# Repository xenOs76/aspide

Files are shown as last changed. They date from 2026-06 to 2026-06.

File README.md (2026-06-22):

# Aspide

<p align="center">
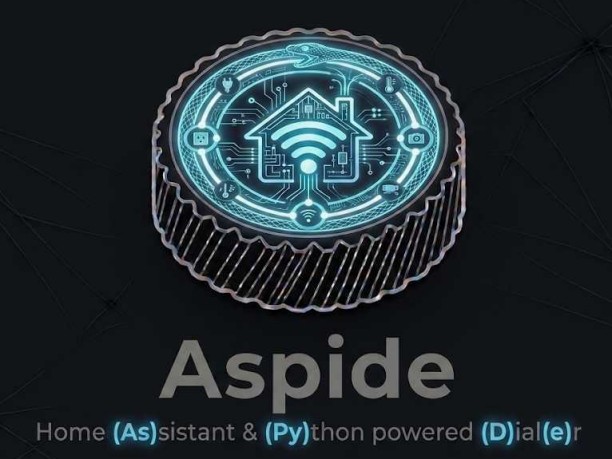
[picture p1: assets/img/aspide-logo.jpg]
Aspide Logo
    
</p>

**Aspide** is a smart, tactile, rotary controller built with
[CircuitPython](https://circuitpython.org/) for the Adafruit QT Py ESP32-S2
board.\
This device provides a physical interface to control
[Home Assistant](https://www.home-assistant.io/) scenes and lights with rich
visual feedback via a NeoPixel strip.

**Aspide** is inspired by two of the many, great, tutorials created by
[Adafruit](https://www.adafruit.com/):

- [USB Rotary Media Dial](https://learn.adafruit.com/usb-rotary-media-dial)
- [Control Wiz Lights With CircuitPython](https://learn.adafruit.com/control-wiz-lights-with-circuitpython/overview)

## Features

- **Triple Control Modes**: Switch between controlling _Home Assistant scenes_,
  _light effects_, and _brightness presets_.
- **NeoPixel Visual Feedback**:
  - Mode indicators (Blue for scenes, Amber for effects, White for brightness).
  - Scene/Effect/Brightness previews with colors matching the selected setting.
- **Home Assistant Integration**: Uses the HA REST API for reliable, low-latency
  control.
- **Manufacturer-Agnostic Light Control**: Controls any HA `light.*` entity
  through Home Assistant — no direct UDP or vendor-specific libraries required.
- **Inactivity Timer**: Automatically dims NeoPixels after a period of
  inactivity to save power and reduce light pollution.
- **HA Health Check**: Periodically verifies Home Assistant connectivity and
  reboots if unreachable after retries (automatic recovery).

## Screenshots

<details>
    <p align="center">
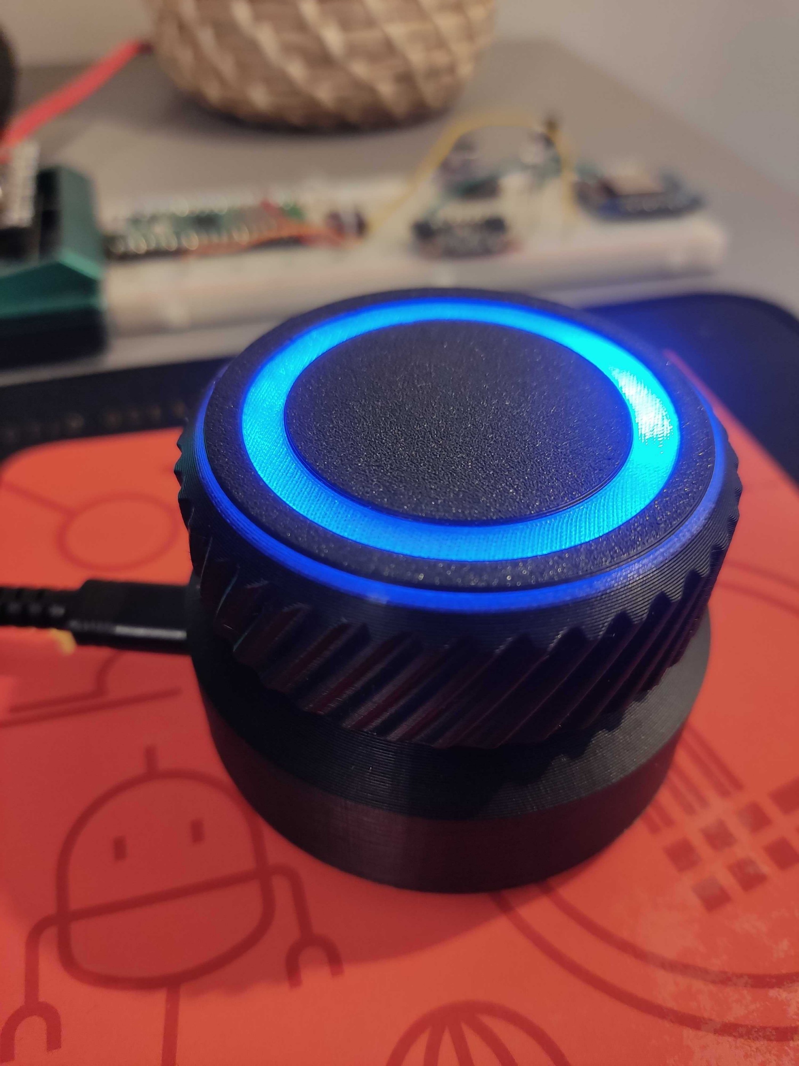
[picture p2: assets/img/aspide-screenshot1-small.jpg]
Aspide Screeenshot 1
        
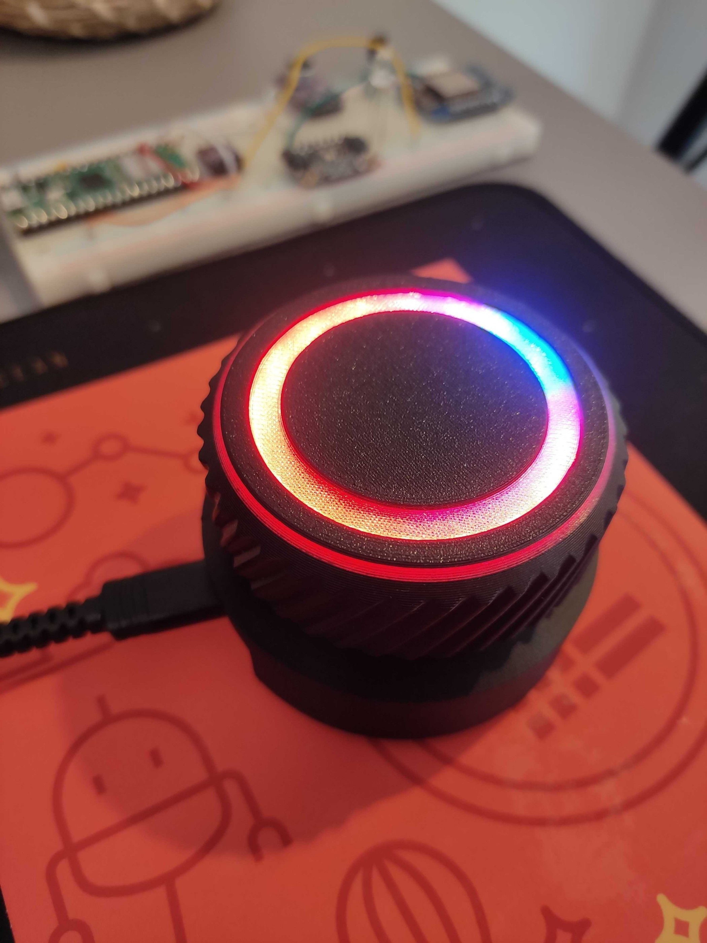
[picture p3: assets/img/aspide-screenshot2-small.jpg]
Aspide Screeenshot 1
        
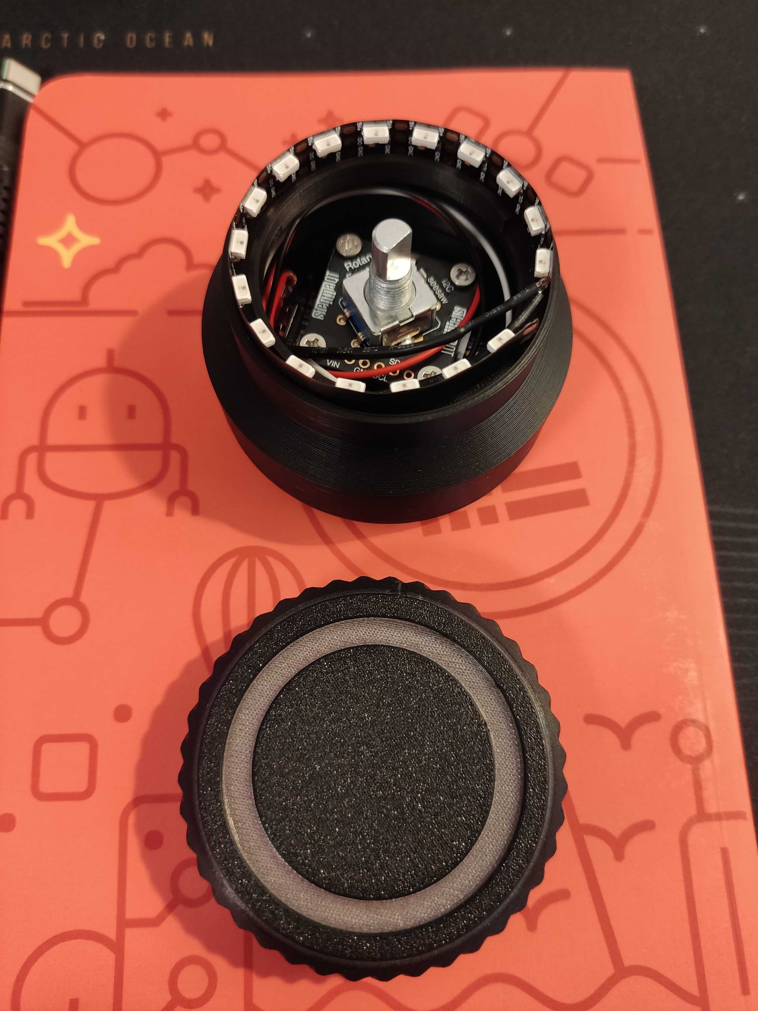
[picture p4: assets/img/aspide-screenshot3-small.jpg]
Aspide Screeenshot 1
        
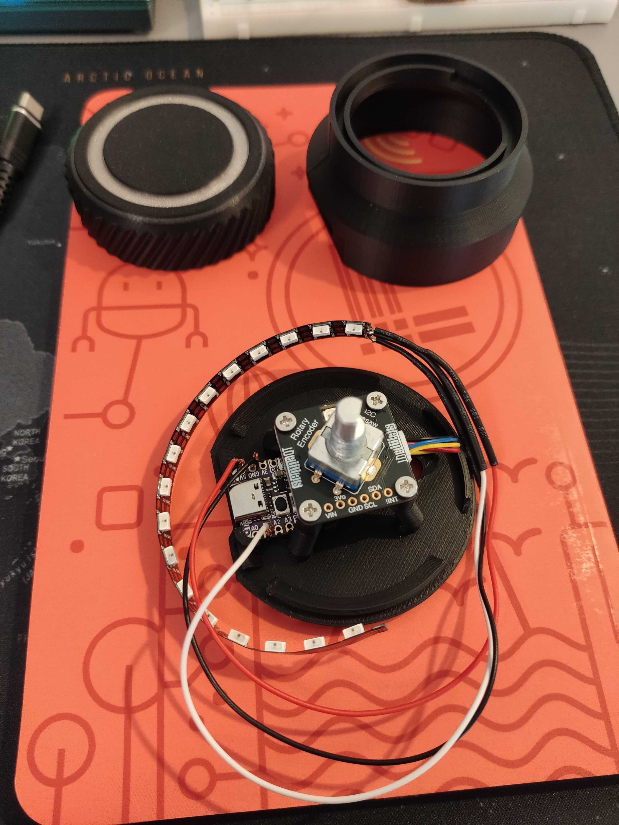
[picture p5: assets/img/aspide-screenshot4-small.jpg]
Aspide Screeenshot 1
        
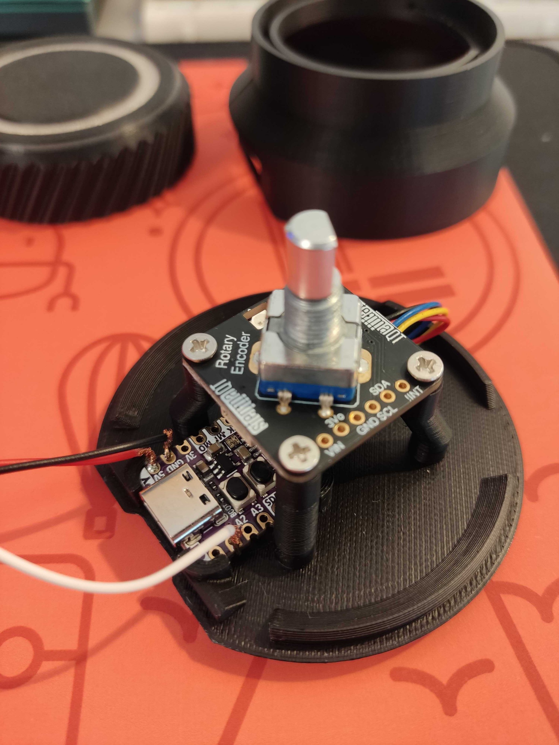
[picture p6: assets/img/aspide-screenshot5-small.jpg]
Aspide Screeenshot 1
        
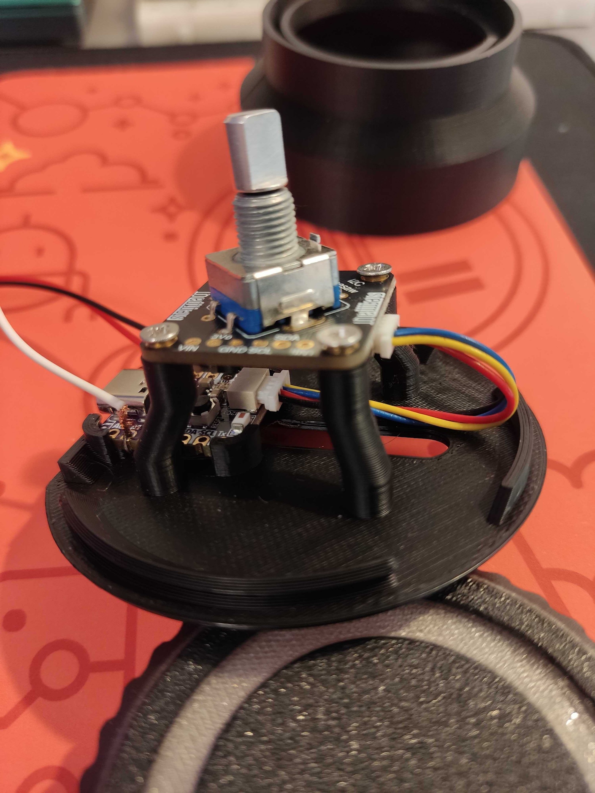
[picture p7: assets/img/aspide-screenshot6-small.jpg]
Aspide Screeenshot 1
        
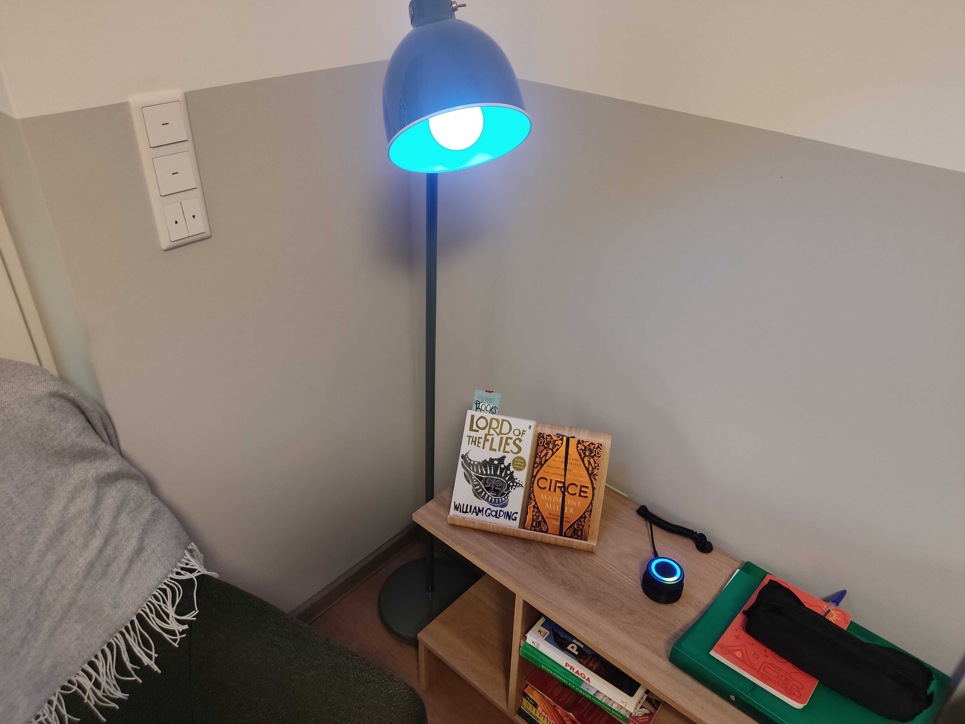
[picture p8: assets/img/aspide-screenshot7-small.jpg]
Aspide Screeenshot 1
        
    </p>
</details>

## Hardware Requirements

- **Microcontroller**:
  [Adafruit QT Py ESP32-S2 WiFi Dev Board with STEMMA QT](https://www.adafruit.com/product/5325)
- **Input**:
  [Adafruit I2C Stemma QT Rotary Encoder Breakout with Encoder - STEMMA QT / Qwiic](https://www.adafruit.com/product/5880)
- **Output**:
  [Adafruit NeoPixel LED Side Light Strip](https://www.adafruit.com/product/3634)
- **STEMMA cable**:
  [STEMMA QT / Qwiic JST SH 4-Pin Cable](https://www.adafruit.com/product/4399)
- **USB cable**:
  [USB A to USB C Cable](https://www.amazon.de/dp/B0D72YLKWL?ref=ppx_yo2ov_dt_b_fed_asin_title&th=1)
- **Power cable**:
  [Stranded-Core Ribbon Cable - 4 Wires](https://www.adafruit.com/product/3891)
  or 3 single cables (stranded)
- **Enclosure**:
  [3D printed case](https://learn.adafruit.com/usb-rotary-media-dial/cad-files)
  for the
  [USB Rotary Media Dial](https://learn.adafruit.com/usb-rotary-media-dial)
- **Enclosure Screws**:
  [4 M2.5 x 6mm steel machine screws](https://www.amazon.de/-/en/dp/B01D4R5A1E?ref=ppx_yo2ov_dt_b_fed_asin_title)

### Cabling

<details>

<p align="center">
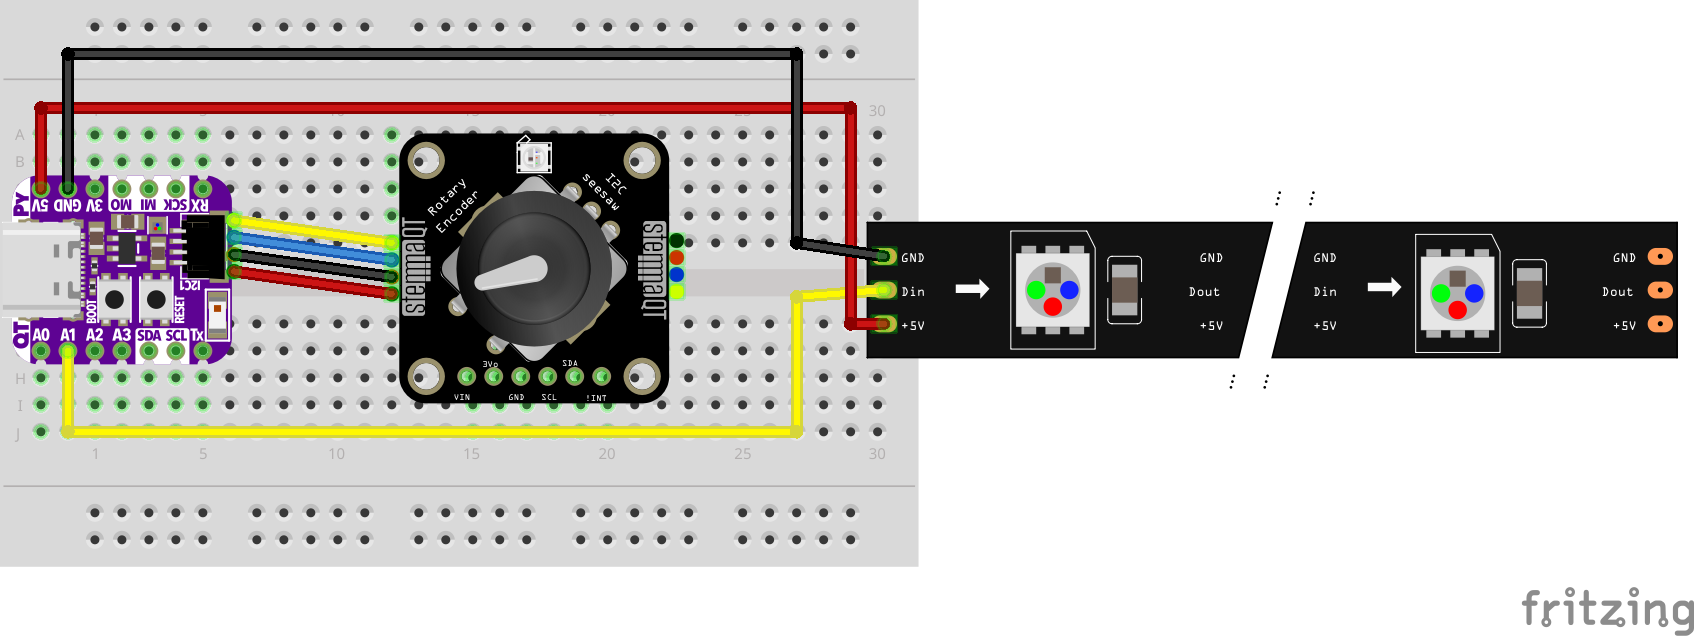
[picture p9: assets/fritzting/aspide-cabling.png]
Aspide Logo
    
</p>

</details>

## Configuration

The device is configured via a `settings.toml` file located in the root of the
`CIRCUITPY` drive.

### WiFi Settings

```toml
CIRCUITPY_WIFI_SSID = "Your_SSID"
CIRCUITPY_WIFI_PASSWORD = "Your_Password"
```

### Home Assistant Settings

To connect to Home Assistant, you need your server URL and a **Long-Lived Access
Token** (generated from your HA user profile).

```toml
HA_URL = "http://192.168.1.78:8123"
HA_TOKEN = "your_long_lived_access_token_here"

# List of HA scenes to iterate through in 'home_assistant' mode
HA_SCENES = "scene.nightlights,scene.lightsoff,scene.atdesk_soft_lights,scene.softlights1"

# Light entity for ha_light and ha_brightness modes
HA_LIGHT_ENTITY_ID = "light.wiz_01"

# Effects to browse in ha_light mode (comma-separated, must match HA effect_list)
# Leave empty to use built-in defaults: Warm White, Daylight, Sunset, Focus
HA_LIGHT_EFFECTS = "Warm White,Daylight,Sunset,Focus"

# NeoPixel preview colors for effects (1:1 with HA_LIGHT_EFFECTS; optional)
HA_LIGHT_EFFECT_COLORS = "bright_yellow,bright_white,dim_orange,dim_green"

# Brightness presets for ha_brightness mode (off=0, low=64, mid=128, high=191, max=255)
HA_LIGHT_BRIGHTNESS = "off,low,mid,high,max"

# Optional NeoPixel preview override (1:1 with HA_LIGHT_BRIGHTNESS)
# If omitted, preview scales white to match each preset's HA brightness
# HA_LIGHT_BRIGHTNESS_COLORS = ""
```

### NeoPixel Customization

Customize the behavior and appearance of the LED ring.

```toml
# Seconds of inactivity before NeoPixels turn off
NEOPIXEL_TIMEOUT = 30

# Colors for HA scenes (maps 1-to-1 with HA_SCENES above)
# Available intensities: bright_, soft_, dim_
# Available colors: white, green, red, blue, purple, cyan, yellow, orange, pink, gold, black
HA_SCENE_COLORS = "dim_blue,black,soft_white,dim_white"
```

## Operation

### Controls

- **Rotate**: Browse through the available scenes, effects, or brightness
  presets. The NeoPixel ring will change color to provide a preview.
- **Single Push**: Activate the currently selected scene, effect, or brightness
  preset.
- **Double Push**: Perform a hard reset of the device (reboots and reconnects to
  WiFi).
- **Long Push**: Cycle through **Home Assistant Mode** (Blue), **Light Effects
  Mode** (Amber), and **Brightness Mode** (White).

### Modes

1. **Home Assistant Mode**: Cycles through the scenes defined in `HA_SCENES`.
   The NeoPixels will match the colors defined in `HA_SCENE_COLORS`.
2. **Light Effects Mode** (`ha_light`): Cycles through effects defined in
   `HA_LIGHT_EFFECTS`, or uses built-in defaults (Warm White, Daylight, Sunset,
   Focus) when empty. Effect names must match what your light integration
   exposes. NeoPixel preview colors come from `HA_LIGHT_EFFECT_COLORS`.
3. **Brightness Mode** (`ha_brightness`): Cycles through five presets in
   `HA_LIGHT_BRIGHTNESS` (default: off, low, mid, high, max — 0% to 100% in 25%
   steps). Single push sends `light.turn_on` with the corresponding brightness
   level. NeoPixel preview scales white to match each preset unless overridden
   via `HA_LIGHT_BRIGHTNESS_COLORS`.

### HA connectivity

Every 5 minutes (configurable via optional `HA_PHONE_HOME_INTERVAL`), the device
pings Home Assistant. If the API is unreachable, it retries twice at 5-second
intervals (reconnecting WiFi if needed), then reboots to recover device-side
network state. If Home Assistant remains down, this cycle repeats each interval
until HA responds.

## Installation

1. [Install CircuitPython on your QT Py ESP32-S2](https://learn.adafruit.com/adafruit-qt-py-esp32-s2/circuitpython)
2. Copy the contents of the `src/` directory to the root of your `CIRCUITPY`
   drive
3. Make sure all the required libraries have been copied into the `lib/` folder
4. Use `settings.sample.toml` as template to configure your `settings.toml`
5. Enjoy!

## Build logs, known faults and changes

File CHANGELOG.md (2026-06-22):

### 0.4.0 (2026-06-22)

- **Periodic HA phone-home**: `HomeAssistantClient.ping()` and
  `RotaryDial.phone_home_assistant()` verify HA connectivity every 5 minutes
  (default); retries twice at 5-second intervals with WiFi reconnect; reboots on
  persistent failure until HA recovers
- Optional `HA_PHONE_HOME_INTERVAL` setting; firmware default
  `DEFAULT_HA_PHONE_HOME_INTERVAL` (300 s) in `utils.py`

### 0.3.0 (2026-06-17)

- **Light effects** curated to four Wiz presets (Warm White, Daylight, Sunset,
  Focus) with matching NeoPixel preview colors; empty `HA_LIGHT_EFFECTS` uses
  built-in defaults instead of auto-fetching full `effect_list`
- **Brightness presets** expanded to five evenly spaced levels
  (off/low/mid/high/max: 0%, 25%, 50%, 75%, 100%); NeoPixel preview scales white
  to match HA brightness
- Sample scene list: `scene.redalert` replaced with `scene.atdesk_soft_lights`;
  NeoPixel preview colors updated (`soft_white`, `dim_white`)

### 0.2.0 (2026-06-17)

### Added

- **Light Effects mode** (`ha_light`): browse and apply HA `light.*` effects via
  `HA_LIGHT_EFFECTS` or auto-fetched `effect_list`
- **Brightness mode** (`ha_brightness`): dim/soft/bright presets via
  `HA_LIGHT_BRIGHTNESS`
- NeoPixel preview colors for effects and brightness (`HA_LIGHT_EFFECT_COLORS`,
  `HA_LIGHT_BRIGHTNESS_COLORS`)
- `AGENTS.md` — project-specific guidance for AI coding agents (commands,
  structure, boundaries)
- HA client support for `light.turn_on` with `effect` and `brightness`; entity
  state and effect list fetching

### Changed

- Replaced Wiz-specific control with manufacturer-agnostic HA light entity
  control (`HA_LIGHT_ENTITY_ID`)
- **Button mapping:** long push cycles modes; double push reboots (was reversed)
- Triple-mode operation: Home Assistant scenes, light effects, brightness
  presets
- NVM state format uses magic byte `0x43` with legacy `0x42` migration
- README and `settings.sample.toml` updated for new modes and config keys

### Removed

- `adafruit-circuitpython-wiz` dependency
- `HA_WIZ_LIGHT_ENTITY_ID` and Wiz-specific code paths

## 0.1.0 (2026-06-13)

### Feat

    Aspide CircuitPython application with rotary encoder and NeoPixel ring control
    Home Assistant scene integration and Wiz light effect support
    Button press detection (single/double/long) with inactivity timeout

### Docs

    Added README with configuration guide and setup instructions

### Chores

    Added project configuration files, development tooling, and environment setup

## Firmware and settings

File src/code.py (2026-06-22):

"""Main entry point for the Aspide firmware.

This script initializes the hardware (Rotary Encoder, NeoPixels, I2C),
manages the WiFi connection, and runs the main event loop for handling
user interactions (rotations, single/double/long pushes) to control
Home Assistant entities.
"""

import time
import microcontroller
import os

from adafruit_seesaw import digitalio, rotaryio, seesaw
import neopixel
import board

from colors import rgb_colors
from timeout import InactivityTimer
from ui import DisplayManager
from utils import ButtonPush, DEFAULT_HA_PHONE_HOME_INTERVAL, RotaryDial

# --- Hardware Initialization ---

i2c = board.STEMMA_I2C()  # Using built-in STEMMA QT connector
seesaw = seesaw.Seesaw(i2c, addr=0x36)
seesaw_product = (seesaw.get_version() >> 16) & 0xFFFF
print(f"Found product {seesaw_product}")

if seesaw_product != 4991:
    print("Warning: Unexpected seesaw product ID. Expected 4991")

# Button setup on seesaw pin 24
seesaw.pin_mode(24, seesaw.INPUT_PULLUP)
button = digitalio.DigitalIO(seesaw, 24)
button_held = False

# NeoPixel Ring setup
pixel_pin = board.A1
num_pixels = 18
strip = neopixel.NeoPixel(pixel_pin, num_pixels, brightness=0.5, auto_write=True)

# --- State Management ---

last_position = -1
position_direction = None
color = 0
color_step = 5

encoder = rotaryio.IncrementalEncoder(seesaw)
push = ButtonPush()
rotary_dial = RotaryDial()

# Custom Scene Color Parsing
ha_scene_colors_str = os.getenv("HA_SCENE_COLORS", "")
ha_scene_colors = (
    [c.strip() for c in ha_scene_colors_str.split(",")] if ha_scene_colors_str else []
)

ha_light_effect_colors_str = os.getenv("HA_LIGHT_EFFECT_COLORS", "")
ha_light_effect_colors = (
    [c.strip() for c in ha_light_effect_colors_str.split(",")]
    if ha_light_effect_colors_str
    else []
)

ha_brightness_colors_str = os.getenv("HA_LIGHT_BRIGHTNESS_COLORS", "")
ha_brightness_colors = (
    [c.strip() for c in ha_brightness_colors_str.split(",")]
    if ha_brightness_colors_str
    else []
)

# Initialize Managers
display = DisplayManager(
    strip, rotary_dial, ha_scene_colors, ha_light_effect_colors, ha_brightness_colors
)
neopixel_timeout = int(os.getenv("NEOPIXEL_TIMEOUT", 30))
timer = InactivityTimer(display, neopixel_timeout)


# --- Startup Sequence ---

strip.fill(rgb_colors["white"])
for p in range(num_pixels):
    strip[p] = rgb_colors["purple"]
    time.sleep(0.02)
strip.fill(rgb_colors["black"])

display.show_connecting_animation()
success = rotary_dial.wifi_connect()
print(f"Connection success: {success}")
if success:
    rotary_dial.initialize_ha()
    rotary_dial.ha_light_power(True)
    rotary_dial.online = True
display.show_connection_status(success)

_ha_phone_home_raw = os.getenv(
    "HA_PHONE_HOME_INTERVAL", str(DEFAULT_HA_PHONE_HOME_INTERVAL)
)
try:
    _ha_phone_home_seconds = int(_ha_phone_home_raw)
except (TypeError, ValueError):
    print(
        "Invalid HA_PHONE_HOME_INTERVAL; "
        f"using default {DEFAULT_HA_PHONE_HOME_INTERVAL}s"
    )
    _ha_phone_home_seconds = DEFAULT_HA_PHONE_HOME_INTERVAL

if _ha_phone_home_seconds <= 0:
    print(
        "HA_PHONE_HOME_INTERVAL must be > 0; "
        f"using default {DEFAULT_HA_PHONE_HOME_INTERVAL}s"
    )
    _ha_phone_home_seconds = DEFAULT_HA_PHONE_HOME_INTERVAL

HA_PHONE_HOME_INTERVAL_NS = _ha_phone_home_seconds * 1_000_000_000
last_ha_phone_home = time.monotonic_ns()

# --- Main Event Loop ---

while True:
    # 1. Handle Encoder Rotation
    position = -encoder.position
    if position > last_position:
        timer.reset()
        position_direction = "increase"
        print(f"Position: {position}")

    if position < last_position:
        timer.reset()
        position_direction = "decrease"
        print(f"Position: {position}")

    if position == last_position:
        position_direction = None

    last_position = position

    if rotary_dial.online and position_direction:
        curr_mode = rotary_dial.mode_current()
        if position_direction == "increase":
            if curr_mode == "ha_light":
                print("Browsing light effects (preview only)...")
                rotary_dial.ha_light_select_next()
            elif curr_mode == "ha_brightness":
                print("Browsing brightness presets (preview only)...")
                rotary_dial.ha_brightness_select_next()
            elif curr_mode == "home_assistant":
                print("Switching to next HA scene...")
                rotary_dial.ha_scene_next()
        else:
            if curr_mode == "ha_light":
                print("Browsing light effects (preview only)...")
                rotary_dial.ha_light_select_prev()
            elif curr_mode == "ha_brightness":
                print("Browsing brightness presets (preview only)...")
                rotary_dial.ha_brightness_select_prev()
            elif curr_mode == "home_assistant":
                print("Switching to previous HA scene...")
                rotary_dial.ha_scene_prev()
        display.update_strip_color()

    # 2. Handle Button Presses
    if not button.value and not button_held:
        timer.reset()
        button_held = True
        push.add_pressed_time(time.monotonic_ns())

    if button.value and button_held:
        button_held = False
        push.add_released_time(time.monotonic_ns())
        print(push.status())

    # Process categorization
    if push.push_single():
        print("Single push detected")
        if rotary_dial.online:
            curr_mode = rotary_dial.mode_current()
            if curr_mode == "home_assistant":
                print("Activating HA Scene...")
                rotary_dial.ha_scene_activate()
            elif curr_mode == "ha_light":
                print("Activating light effect via HA...")
                rotary_dial.ha_light_apply_effect()
            elif curr_mode == "ha_brightness":
                print("Applying brightness preset via HA...")
                rotary_dial.ha_brightness_apply()
        push.reset_push()

    if push.push_double():
        print("Double push detected - Rebooting device...")
        # Visual feedback for reboot
        strip.fill(rgb_colors["red"])
        time.sleep(0.5)
        strip.fill(rgb_colors["black"])
        time.sleep(0.2)
        # Final save before reset to ensure NVM is up to date
        rotary_dial.save_state()
        microcontroller.reset()

    if push.push_long():
        print("Long push detected")
        if rotary_dial.online:
            rotary_dial.mode_next()
            curr_mode = rotary_dial.mode_current()
            print(f"\tSwitched to mode: {curr_mode}")
            if curr_mode == "ha_light":
                rotary_dial.ha_light_apply_effect()
            elif curr_mode == "ha_brightness":
                rotary_dial.ha_brightness_apply()
            display.update_strip_color()
        push.reset_push()

    # 3. Handle NeoPixel Timeout (Auto-Dim)
    timer.check()

    # 4. Periodic HA phone-home health check
    if (
        rotary_dial.online
        and time.monotonic_ns() - last_ha_phone_home >= HA_PHONE_HOME_INTERVAL_NS
    ):
        last_ha_phone_home = time.monotonic_ns()
        if not rotary_dial.phone_home_assistant():
            strip.fill(rgb_colors["red"])
            time.sleep(0.5)
            strip.fill(rgb_colors["black"])
            time.sleep(0.2)
            rotary_dial.save_state()
            microcontroller.reset()

    time.sleep(0.01)  # Prevent CPU hogging

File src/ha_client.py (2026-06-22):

import adafruit_requests
import json


class HomeAssistantClient:
    """Client for interacting with the Home Assistant REST API.

    This client provides high-level methods to trigger scenes, toggle lights,
    and call generic services through the Home Assistant API.

    Args:
        pool (socketpool.SocketPool): A socket pool for network communication.
        ssl_context (ssl.SSLContext): SSL context for secure HTTPS requests.
    """

    def __init__(self, pool, ssl_context):
        import os

        self._url = os.getenv("HA_URL")
        self._token = os.getenv("HA_TOKEN")
        self._scenes = os.getenv("HA_SCENES", "").split(",")
        self._requests = adafruit_requests.Session(pool, ssl_context)
        self._headers = {
            "Authorization": f"Bearer {self._token}",
            "Content-Type": "application/json",
        }

    def fetch_scenes(self):
        """Retrieves the list of scenes configured in the settings.

        Returns:
            list[str]: A list of scene entity IDs (e.g., ['scene.daytime', 'scene.night']).
        """
        return [s.strip() for s in self._scenes if s.strip()]

    def activate_scene(self, scene_id):
        """Activates a specific Home Assistant scene.

        Args:
            scene_id (str): The entity ID of the scene to activate (e.g., 'scene.nightlights').

        Returns:
            bool: True if the scene was activated successfully, False otherwise.
        """
        if not self._url or not self._token:
            return False

        url = f"{self._url}/api/services/scene/turn_on"
        data = {"entity_id": scene_id}
        try:
            response = self._requests.post(
                url, headers=self._headers, data=json.dumps(data)
            )
            if response.status_code == 200:
                print(f"Scene {scene_id} activated successfully.")
                return True
            else:
                print(f"Failed to activate scene. Status code: {response.status_code}")
                return False
        except Exception as e:
            print(f"Error activating scene: {e}")
            return False

    def call_service(self, domain, service, service_data):
        """Calls a generic Home Assistant service.

        Args:
            domain (str): The integration domain (e.g., 'light', 'switch').
            service (str): The service name (e.g., 'turn_on', 'toggle').
            service_data (dict): The payload for the service call.

        Returns:
            bool: True if the service call was successful, False otherwise.
        """
        if not self._url or not self._token:
            return False

        url = f"{self._url}/api/services/{domain}/{service}"
        try:
            response = self._requests.post(
                url, headers=self._headers, data=json.dumps(service_data)
            )
            if response.status_code == 200:
                print(f"Service {domain}.{service} called successfully.")
                return True
            else:
                print(f"Failed to call service. Status code: {response.status_code}")
                return False
        except Exception as e:
            print(f"Error calling service: {e}")
            return False

    def light_turn_on(self, entity_id, brightness=None, effect=None):
        """Turns on a light entity with optional parameters.

        Args:
            entity_id (str): The entity ID of the light.
            brightness (int, optional): Brightness level (0-255).
            effect (str, optional): The name of the effect to apply (e.g., 'Pulse', 'Ocean').

        Returns:
            bool: True if the command was successful.
        """
        data = {"entity_id": entity_id}
        if brightness is not None:
            data["brightness"] = brightness
        if effect is not None:
            data["effect"] = effect
        return self.call_service("light", "turn_on", data)

    def light_turn_off(self, entity_id):
        """Turns off a light entity.

        Args:
            entity_id (str): The entity ID of the light.

        Returns:
            bool: True if the command was successful.
        """
        data = {"entity_id": entity_id}
        return self.call_service("light", "turn_off", data)

    def ping(self, timeout=10):
        """Checks whether the Home Assistant API is reachable.

        Args:
            timeout (float): Request timeout in seconds.

        Returns:
            bool: True if the API responded with HTTP 200.
        """
        if not self._url or not self._token:
            return False

        url = f"{self._url}/api/"
        try:
            response = self._requests.get(url, headers=self._headers, timeout=timeout)
            if response.status_code == 200:
                return True
            print(f"HA ping failed. Status code: {response.status_code}")
            return False
        except Exception as e:
            print(f"HA ping error: {e}")
            return False

    def fetch_light_effects(self, entity_id):
        """Retrieves the effect_list from a light entity state.

        Args:
            entity_id (str): The entity ID of the light.

        Returns:
            list[str]: Effect names from HA, or empty list on error.
        """
        if not self._url or not self._token or not entity_id:
            return []

        url = f"{self._url}/api/states/{entity_id}"
        try:
            response = self._requests.get(url, headers=self._headers)
            if response.status_code != 200:
                print(
                    f"Failed to fetch light state. Status code: {response.status_code}"
                )
                return []
            state = response.json()
            effects = state.get("attributes", {}).get("effect_list", [])
            if effects:
                print(f"Fetched {len(effects)} effects from {entity_id}")
            return list(effects)
        except Exception as e:
            print(f"Error fetching light effects: {e}")
            return []

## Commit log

2026-06-13 feat: initial import
    [aspide-cabling.fzz]
2026-06-17 bump: version 0.1.0 → 0.2.0
2026-06-17 bump: version 0.2.0 → 0.3.0
2026-06-22 fix: validate HA_PHONE_HOME_INTERVAL input and ensure fallback to default
    [code.py]
2026-06-22 bump: version 0.3.0 → 0.4.0
